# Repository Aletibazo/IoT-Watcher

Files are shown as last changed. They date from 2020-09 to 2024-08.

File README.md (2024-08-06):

# IoT-Watcher

Open source monitoring system for IT infrastructures using IoT sensors.

Related paper: https://doi.org/10.1007/978-3-031-48590-9_15

## Motivation

In Data Centers there are usually monitoring solutions offered by the manufacturer, which integrate all the equipment and sensors that make up the solution in a single system. In the CITIC data centre, all the sensors are integrated into an APC system that allows the thresholds of each type of sensor to be managed and alerts to be configured.

These proprietary solutions work very well, but it is difficult to add external elements to these systems, since they have closed APIs and it is difficult to obtain the appropriate documentation. In the specific case of the CITIC, it is desired to be able to integrate the monitoring of the servers housed in the CPD cabinets together with the monitoring of the environmental parameters of the room, thus centralising all the elements that make up the CPD and that are managed by the administrator.

## Description

This project aims to develop an open, multi-platform system that allows for the addition of different types of sensors and machines. With this secondary objective in mind, developments will be made on open hardware platforms for the sensor part and, whenever possible, open-source operating systems, libraries, external programs, etc. will be used with the goal of having a system that is as open and compatible as possible.

The monitoring server will be based on Zabbix, a widely used monitoring tool in the systems world. In the first phase, servers will be added to this system using the Zabbix agents for Windows, Linux and VMware, and their correct operation will be checked by taking data and comparing it with the servers themselves. The monitoring server forms the basis of the project, and once it is deployed and tested, the sensor section will be developed.

Sensors compatible with open-source and open-hardware Arduino boards will be used, always keeping in mind that the sensors used in this project can be replaced by others with similar characteristics. In the particular case of this project, temperature, humidity, presence and electrical consumption sensors will be used. First, the Arduino program will be developed to read data from the sensors and send it to a Raspberry Pi that will be responsible for centralizing the data from all the Arduinos in the infrastructure and sending it to the Zabbix server. Then each sensor will be placed in its corresponding place in the DC, for which issues such as autonomy, placement in racks, etc. will be taken into account.

An open-source application with the MQTT protocol will be used for data transmission between the Arduinos and the Raspberry Pi. With the rise of the IoT, multiple open-source projects have emerged to control home automation elements, so one of these projects will be used to collect all the data from the sensors and the necessary functionalities will be added to send the data to the configured Zabbix server. To achieve this communication between Raspberry and Zabbix, a specific agent will be developed.

The possibility of implementing a prediction system based on Machine Learning models that launches alerts of possible failures in the infrastructure will be considered. The system is intended to be able to alert of failures that may occur in all elements of the DC - from end-of-life warnings for disks to possible failures in the cooling system - based on historical data and real-time data.

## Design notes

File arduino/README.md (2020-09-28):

# TFM_arduinos
NodeMCU code to connect to a MQTT broker securely using TLS and sending sensors data to specified topics and displaying in on a 0.96" OLED.

You need to upload client certificate and private key as well as CA certificate into your NodeMCU's file system. Do this using ESP8266 filesystem uploader:
https://github.com/esp8266/arduino-esp8266fs-plugin
NOTE: these files must have read permissions.

Inside nodemcu_DHT22 there's code to configure a DHT22 temperature & humidity sensor.

Detailed instrucctions can be found inside each program's code.

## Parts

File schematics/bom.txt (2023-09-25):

Partlist exported from /Users/Ale/Documents/EAGLE/projects/sensor_esp8266/untitled.sch at 12/5/21 13:36

Qty Value                   Device                  Package                    Parts                  Description                                         MF         MPN      OC_FARNELL OC_NEWARK POPULARITY SPICEPREFIX
2                           10-XX                   B3F-10XX                   FLASH, RESET           OMRON SWITCH                                                   B3F-1000 176432     36M3542                         
1                           JP1E                    JP1                        TX/RX                  JUMPER                                                                                       61                    
1   100nF                   C-EUC0805               C0805                      C1                     CAPACITOR, European symbol                                                                                         
1   100nF                   CPOL-EUR/2012-12R       R/2012-12R                 C2                     POLARIZED CAPACITOR, European symbol                                                                               
1   10uF                    C-EUC0805               C0805                      C4                     CAPACITOR, European symbol                                                                                         
1   10uF 25V                C-EUC0805               C0805                      C3                     CAPACITOR, European symbol                                                                                         
4   12K                     R-US_R1206              R1206                      R2, R3, R4, R5         RESISTOR, American symbol                                                                                          
1   12K                     R-US_R1206              R1206                      R1                     RESISTOR, American symbol                                                                               R          
1   DISPLAY-OLED-128X64-I2C DISPLAY-OLED-128X64-I2C DISPLAY-OLED-128X64-I2C    OLED                   128x64 Dot Matrix OLED Module based on SSD1306 chip                                                                
1   ESP-12E/F               ESP-12E/F               ESP-12E                    IC1                                                                                                                                       
1   HT7333                  HT7333                  SOT-89                     HT7333                                                                                                                                    
4   JST-XH-03-PIN-LONG-PAD  JST-XH-03-PIN-LONG-PAD  JST-XH-03-PACKAGE-LONG-PAD 1W, LED, PIR, TEMP     JST XH Connector 2 Pin                                                                                             
1   JST-XH-07-PIN-LONG-PAD  JST-XH-07-PIN-LONG-PAD  JST-XH-07-PACKAGE-LONG-PAD D5/D6/D7/D8/GND/3V3/5V JST XH Connector 2 Pin                                                                                             
1   MICRO-USBV2             MICRO-USBV2             MICRO-USB-2                USB                    Micro USB B connector                                                                                              
1   SMAJ5.0A                SMAJ5.0A                DO214AC                    D1                     SMAJ Series TVS Diodes                              Littelfuse SMAJ5.0A 1827607    71J2029

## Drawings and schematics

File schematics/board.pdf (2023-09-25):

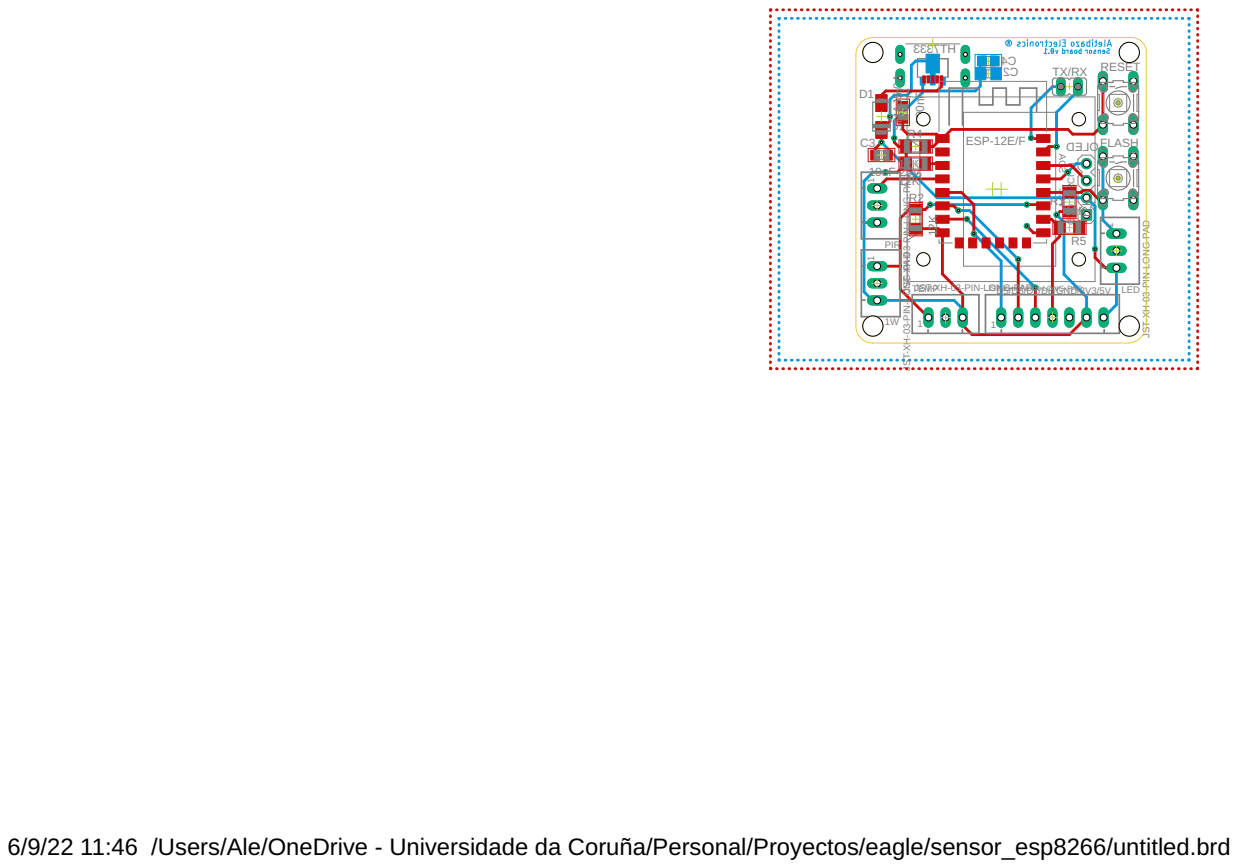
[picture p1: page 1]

JST-XH-03-PIN-LONG-PAD

TEMP

JST-XH-07-PIN-LONG-PAD

6/9/22 11:46 /Users/Ale/OneDrive - Universidade da Coruña/Personal/Proyectos/eagle/sensor_esp8266/untitled.brd

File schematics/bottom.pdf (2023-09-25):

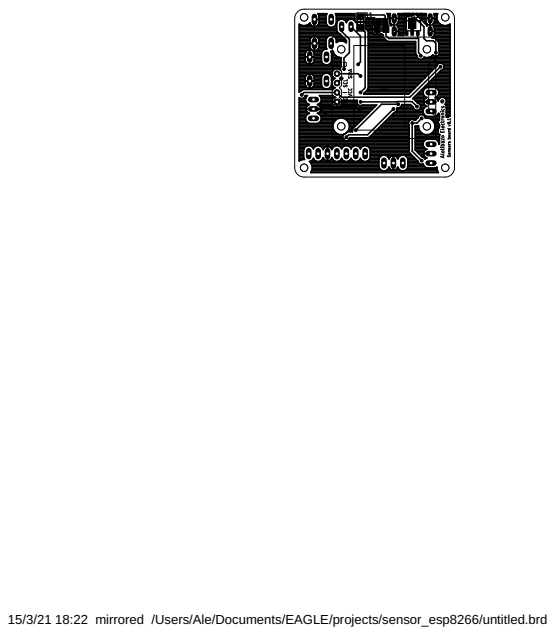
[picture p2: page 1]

15/3/21 18:22 mirrored /Users/Ale/Documents/EAGLE/projects/sensor_esp8266/untitled.brd

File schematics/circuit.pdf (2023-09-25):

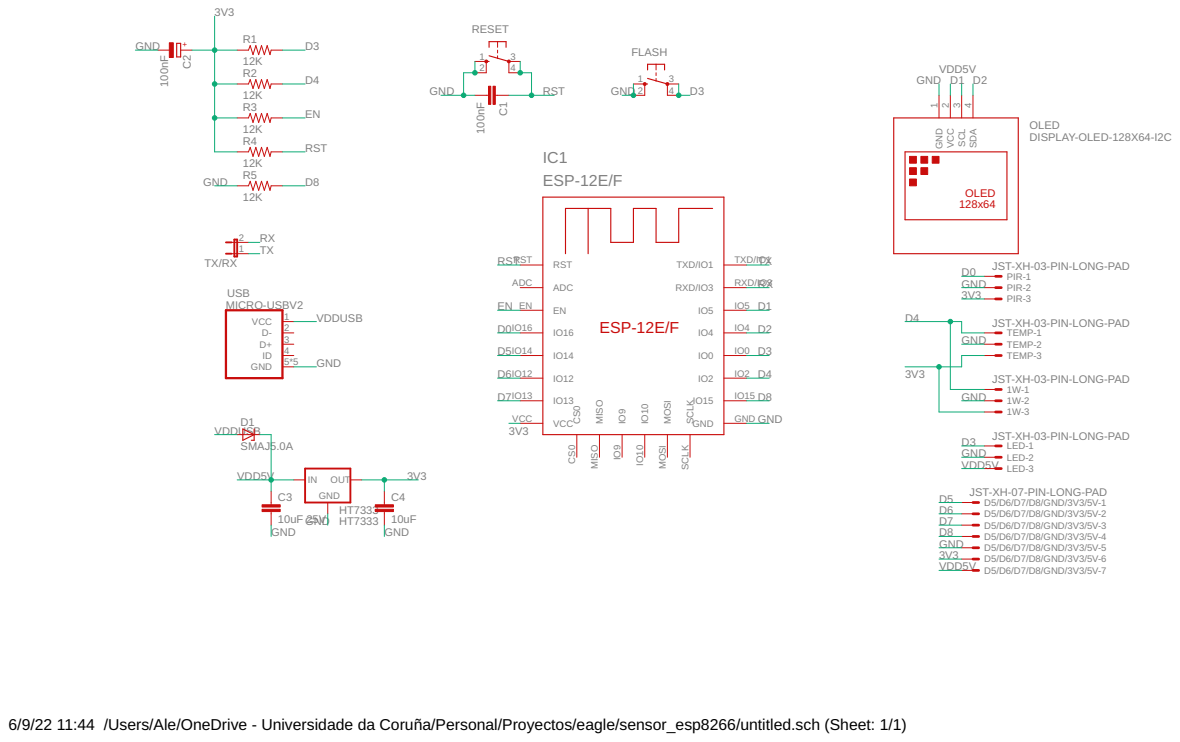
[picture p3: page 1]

JST-XH-03-PIN-LONG-PAD
TEMP-1 TEMP-2 TEMP-3

6/9/22 11:44 /Users/Ale/OneDrive - Universidade da Coruña/Personal/Proyectos/eagle/sensor_esp8266/untitled.sch (Sheet: 1/1)

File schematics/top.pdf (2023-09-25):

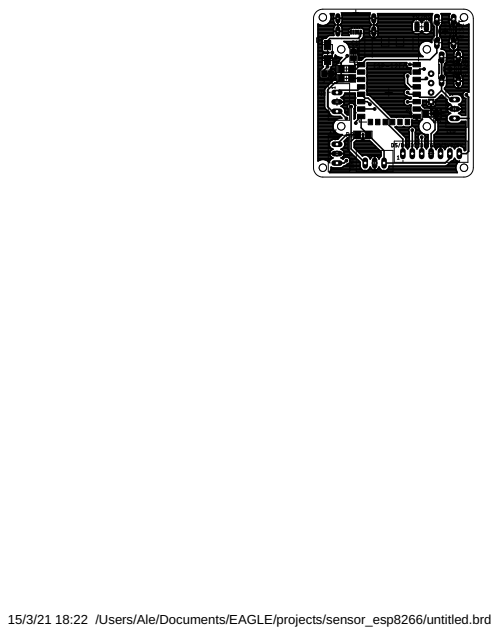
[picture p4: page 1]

15/3/21 18:22 /Users/Ale/Documents/EAGLE/projects/sensor_esp8266/untitled.brd


15/3/21 18:22 mirrored /Users/Ale/Documents/EAGLE/projects/sensor_esp8266/untitled.brd

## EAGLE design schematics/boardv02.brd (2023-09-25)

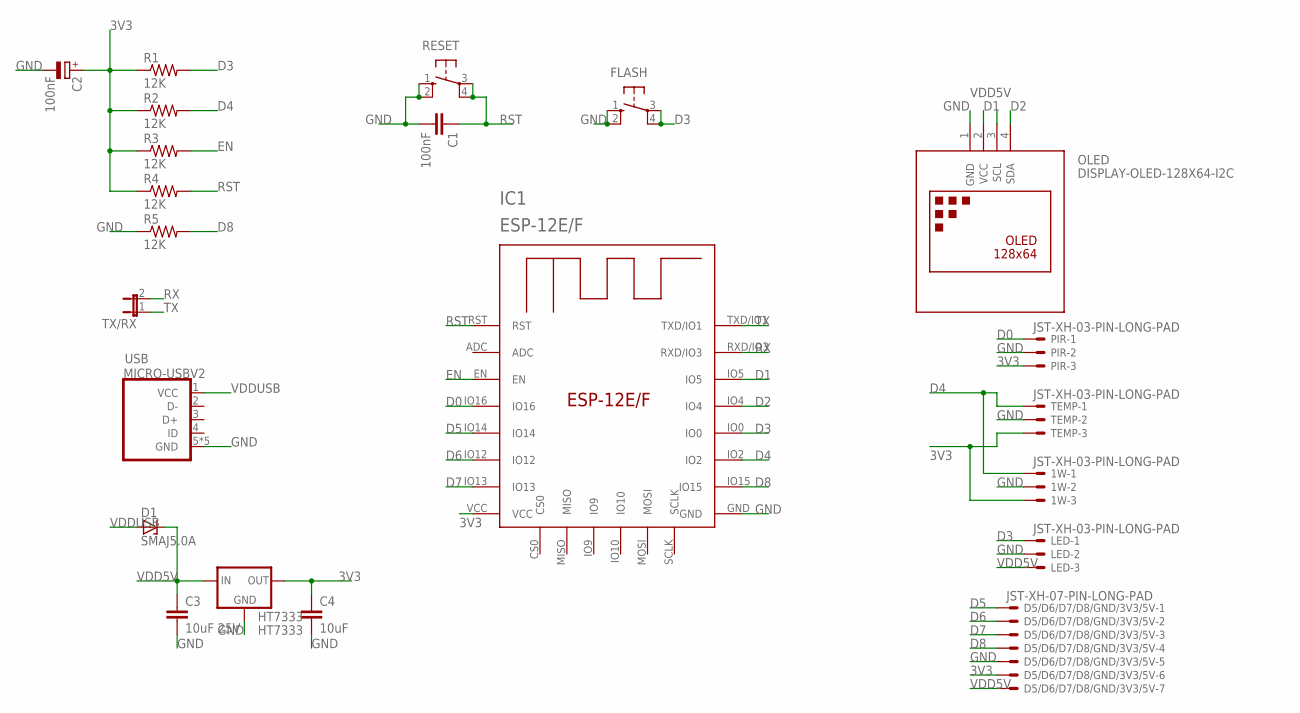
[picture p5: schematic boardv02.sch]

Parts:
1W: JST-XH-03-PIN-LONG-PAD; JST-XH-03-PACKAGE-LONG-PAD
C1: 100nF; C0805
C2: 100nF; R/2012-12R
C3: 10uF 25V; C0805
C4: 10uF; C0805
D1: SMAJ5.0A; DO214AC
D5/D6/D7/D8/GND/3V3/5V: JST-XH-07-PIN-LONG-PAD; JST-XH-07-PACKAGE-LONG-PAD
FLASH: 10-XX; B3F-10XX
HT7333: HT7333; SOT-89
IC1: ESP-12E/F; ESP-12E
LED: JST-XH-03-PIN-LONG-PAD; JST-XH-03-PACKAGE-LONG-PAD
OLED: DISPLAY-OLED-128X64-I2C
PIR: JST-XH-03-PIN-LONG-PAD; JST-XH-03-PACKAGE-LONG-PAD
R1, R2, R3, R4, R5: 12K; R1206
RESET: 10-XX; B3F-10XX
TEMP: JST-XH-03-PIN-LONG-PAD; JST-XH-03-PACKAGE-LONG-PAD
TX/RX: JP1E; JP1
USB: MICRO-USBV2; MICRO-USB-2

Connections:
3V3: 1W.3, C2.+, C4.1, D5/D6/D7/D8/GND/3V3/5V.6, HT7333.1 (OUT), IC1.VCC, PIR.3, R1.1, R2.1, R3.1, R4.1, TEMP.3
D0: IC1.IO16, PIR.1
D1: IC1.IO5, OLED.3 (SCL)
D2: IC1.IO4, OLED.4 (SDA)
D3: FLASH.3, FLASH.4 (P1), IC1.IO0, LED.1, R1.2
D4: 1W.1, IC1.IO2, R2.2, TEMP.1
D5: D5/D6/D7/D8/GND/3V3/5V.1, IC1.IO14
D6: D5/D6/D7/D8/GND/3V3/5V.2, IC1.IO12
D7: D5/D6/D7/D8/GND/3V3/5V.3, IC1.IO13
D8: D5/D6/D7/D8/GND/3V3/5V.4, IC1.IO15, R5.2
EN: IC1.EN, R3.2
GND: 1W.2, C1.2, C2.-, C3.2, C4.2, D5/D6/D7/D8/GND/3V3/5V.5, FLASH.1 (S), FLASH.2 (S1), HT7333.2 (GND), IC1.GND, LED.2, OLED.1 (GND), PIR.2, R5.1, RESET.1 (S), RESET.2 (S1), TEMP.2, USB.5 (GND), USB.P$1 (GND), USB.P$2 (GND), USB.P$3 (GND), USB.P$4 (GND)
RST: C1.1, IC1.RST, R4.2, RESET.3, RESET.4 (P1)
RX: IC1.RXD/IO3, TX/RX.2
TX: IC1.TXD/IO1, TX/RX.1
VDD5V: C3.1, D1.C, D5/D6/D7/D8/GND/3V3/5V.7, HT7333.3 (IN), HT7333.4 (IN), LED.3, OLED.2 (VCC)
VDDUSB: D1.A, USB.1 (VCC)

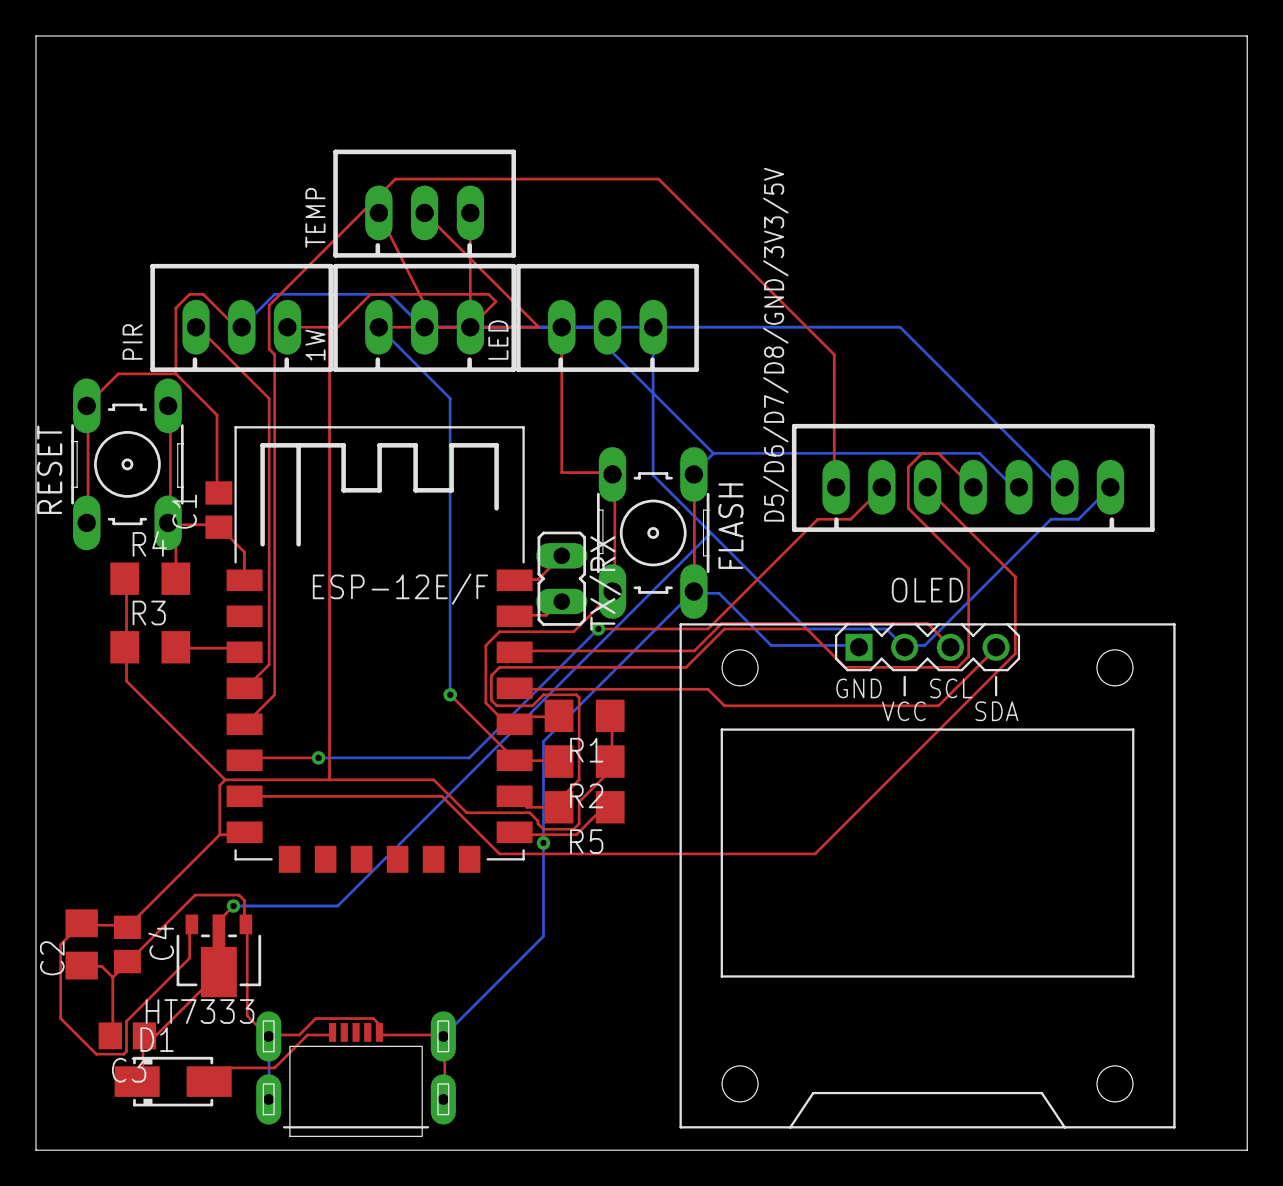
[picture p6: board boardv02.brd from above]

Board: 2 copper layers, 67.3 x 61.9 mm, 22 parts (0 on the bottom side), 17 nets.

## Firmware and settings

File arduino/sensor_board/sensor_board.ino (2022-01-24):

/*
* This is the firmware for Aletibazo Electronics Sensor Board v0.1
* 
* Pinout correspondence between the board and the ESP8266:
*   * PIR      -> D0
*   * LED      -> D3
*   * 1W, TEMP -> D4
*   * HUMIDITY -> D5
*   
* This program connects to a MQTT broker using TLS
* and sends data from DS18B20, DHT22 and PIR sensors to specified topics. It also
* displays sensors data and other info on a 128x32 OLED display.
* 
* Don't forget to set variables to connect to access point and MQTT broker.
* You need to upload client.crt, client.key and ca.crt to Node MCU's file system.
* These need to be issued by your broker's server, as detailed here:
* https://gitlab.citic.udc.es/a.mosteiro/tfm/-/wikis/Aplicaciones-dom%C3%B3tica
* To upload files to the file system, follow this guide: 
* https://github.com/esp8266/arduino-esp8266fs-plugin
* 
* Note that MQTTServer variable must be a domain name, not an IP address.
* IPSET_DNS must be a DNS server that can resolve your broker's name.
* 
* Author: Ale Mosteiro
* Mail:   a.mosteiro@udc.es
* 
*/

#include <ESP8266WiFi.h>
#include <PubSubClient.h>
#include <Wire.h>
#include <DallasTemperature.h>
#include <OneWire.h>
#include <U8g2lib.h>
#include <SPI.h>
#include <DHTesp.h>

// PIR sensor is connected to pin D0
int PIR_SENSOR = D0;
// DHT11 sensor connected to pin D5
int DHT_SENSOR = D5;
DHTesp dht;

// Data wire is plugged into pin D4 on the NodeMCU
#define ONE_WIRE_BUS D4
// Setup a oneWire instance to communicate with any OneWire devices 
// (not just Maxim/Dallas temperature ICs)
OneWire oneWire(ONE_WIRE_BUS);
// Pass our oneWire reference to Dallas Temperature.
DallasTemperature sensors(&oneWire);

// Set OLED type
U8G2_SSD1306_128X32_UNIVISION_F_HW_I2C u8g2(U8G2_R0);

/**
 * Customize this settings 
 */
const char* ssid = "SSID-Name";
const char* password = "SSID-Password";
#define IPSET_STATIC { xxx, xxx, xxx, xxx }
#define IPSET_GATEWAY { xxx, xxx, xxx, xxx }
#define IPSET_SUBNET { xxx, xxx, xxx, xxx }
#define IPSET_DNS { xxx, xxx, xxx, xxx }


// TODO Change this to parametrize ClientName so it needs to be replaced only once
const char* ClientName = "RackNumber";
const char* MQTTServer = "your-domain.org";

char* TopicSub = "cpd/RackNumber/led";
char* TopicConfigTemp = "cpd/sensor/RackNumberTemp/config";
char* PayloadConfigTemp = "{\"device_class\": \"temperature\", \"name\": \"RackNumberTemperature\", \"state_topic\": \"cpd/sensor/RackNumber/state\", \"unit_of_measurement\": \"°C\", \"value_template\": \"{{ value_json.temperature }}\" }";
char* TopicConfigHumdt = "cpd/sensor/RackNumberHumdt/config";
char* PayloadConfigHumdt = "{\"device_class\": \"humidity\", \"name\": \"RackNumberHumidity\", \"state_topic\": \"cpd/sensor/RackNumber/state\", \"unit_of_measurement\": \"%\", \"value_template\": \"{{ value_json.humidity }}\" }";
char* StateTopic = "cpd/sensor/RackNumber/state";
char* TopicConfigPIR = "cpd/binary_sensor/RackNumberPIR/config";
char* PayloadConfigPIR = "{\"device_class\": \"motion\", \"name\": \"RackNumberPIR\", \"state_topic\": \"cpd/binary_sensor/RackNumberPIR/state\" }";
char* StateTopicPIR = "cpd/binary_sensor/RackNumberPIR/state";

/**
 * End of customization
 */

byte IPStatic[] = IPSET_STATIC;
byte IPGateway[] = IPSET_GATEWAY;
byte IPSubnet[] = IPSET_SUBNET;
byte IPDNS[] = IPSET_DNS;
  
WiFiClientSecure ESPClient;
PubSubClient client(MQTTServer, 8883, ESPClient);

int lastMsg = 0;
boolean configured = false;

char msg[50];

float t;
float h;
char buff[5];

int buttonState = 0;

void setup() {
  pinMode(LED_BUILTIN, OUTPUT);     // Initialize the LED_BUILTIN pin as an output
  
  Serial.begin(115200);

  u8g2.begin();
  dht.setup(DHT_SENSOR, DHTesp::DHT11);

  printInfo("Setting up...");
  // Connect WiFi
  printInfo("Connecting WiFi");
  setupWiFi();
  delay(1000);
  // Get time from SNTP Server
  printInfo("Get SNTP time");
  getTime();
  delay(1000);

  // Load certs for TLS
  printInfo("Load certs");
  loadCerts();
  delay(1000);
  
  //dht.begin();
  sensors.begin();

  client.setCallback(callback);
}

void loop() {  
  if (!client.connected()) {
    printInfo("Connect broker");
    reconnect();
  }
  client.loop();

  long now = millis();

  // Send sensor config on power on
  if (!configured) {
    configured = true;

    sendmqttMsg(TopicConfigTemp, PayloadConfigTemp);
    sendmqttMsg(TopicConfigHumdt, PayloadConfigHumdt);
    sendmqttMsg(TopicConfigPIR, PayloadConfigPIR);
  }
  
  // Send sensors data every 5 sec
  if (now - lastMsg > 5000) {
    String payload = String();
    lastMsg = now;

    // Obtain temperature from DS18B20 1-wire sensor
    sensors.requestTemperatures();
    t = sensors.getTempCByIndex(0);
    // Add temperature to payload
    payload = "{ \"temperature\": " + String(t, 2);
    // Obtain humidity from DHT22 sensor
    h = dht.getHumidity();
    // If we can't get data from the sensor, we send -127
    String hmdt = (isnan(h) == 1) ? "-127" : String(h, 2);
    // Add humidity to payload
    payload = payload + ", \"humidity\": ";
    payload = payload + hmdt;
    // Add presence to payload, getting value from digital pin
    // Close payload string, send it to StateTopic MQTT topic
    payload = payload + " }";
    // Send MQTT payload for temperature and humidity
    sendmqttMsg(StateTopic, payload);

    // Prepare payload for PIR, reading data from DHT22
    String motion = (digitalRead(PIR_SENSOR) == 1) ? "ON" : "OFF";
    payload = "{ \"state\": \"" + motion;
    // Close payload string, send it to StateTopic MQTT topic
    payload = payload + "\" }";
    // Send MQTT payload for PIR
    sendmqttMsg(StateTopicPIR, motion);
    
    
    // Print data to OLED
    printData(t, h);
    
  }
}

// Function to display set up information
// Given char must be 16chars max
void printInfo(const char *s){
  u8g2.clearBuffer();
  u8g2.setFont(u8g2_font_t0_16_tf);
  u8g2.drawStr(0, 12, ClientName);
  u8g2.drawStr(0, 24, s);
  u8g2.sendBuffer();
}
// Function to display set up information
// Given char must be 16chars max
void printData(float temperature, float humidity){
  u8g2.clearBuffer();
  u8g2.setFont(u8g2_font_t0_16_tf);
  u8g2.setCursor(0, 12);
  u8g2.print(ClientName);
  u8g2.setFont(u8g2_font_profont10_tf);
  u8g2.setCursor(0, 20);
  u8g2.print("T: ");
  u8g2.print(temperature);
  u8g2.print(" C");
  u8g2.setCursor(0, 28);
  u8g2.print("H: ");
  u8g2.print(humidity);
  u8g2.print(" %");
  u8g2.sendBuffer();
}


void setupWiFi() {

  delay(10);
  // We start by connecting to a WiFi network
  Serial.println();
  Serial.print("Connecting to ");
  Serial.println(ssid);

  WiFi.mode(WIFI_STA);
  WiFi.begin(ssid, password);
  WiFi.disconnect();

  WiFi.begin(ssid, password);
  WiFi.config(IPAddress(IPStatic), IPAddress(IPGateway), IPAddress(IPSubnet), IPAddress(IPDNS));
  while (WiFi.status() != WL_CONNECTED) {
    delay(500);
    Serial.print(".");
  }

  Serial.println("");
  Serial.println("WiFi connected");
  Serial.println("IP address: ");
  Serial.println(WiFi.localIP());
}

void getTime(){
  // Synchronize time using SNTP. This is necessary to verify that
  // the TLS certificates offered by the server are currently valid.
  Serial.print("Setting time using SNTP");
  configTime(8 * 3600, 0, "es.pool.ntp.org");
  time_t now = time(nullptr);
  while (now < 1000) {
    delay(500);
    Serial.print(".");
    now = time(nullptr);
  }
  Serial.println("");
  struct tm timeinfo;
  gmtime_r(&now, &timeinfo);

  Serial.print("Current time: ");
  Serial.print(asctime(&timeinfo));
  printInfo(asctime(&timeinfo));
}

// Load Certificates
void loadCerts() {
  
  if (!SPIFFS.begin()) {
   Serial.println("Failed to mount file system");
   return;
  }
  
  // Load client certificate file from SPIFFS
  File cert = SPIFFS.open("/client.crt", "r"); //replace client.crt with your uploaded file name
  if (!cert)
    Serial.println("Failed to open cert file");
  else
    Serial.println("Success to open cert file");

  delay(1000);

  // Set client certificate
  if (ESPClient.loadCertificate(cert)){
    Serial.println("cert loaded");
  } else
    Serial.println("cert not loaded");

  // Load client private key file from SPIFFS
  File private_key = SPIFFS.open("/client.key", "r"); //replace client.key with your uploaded file name
  if (!private_key)
    Serial.println("Failed to open private cert file");
  else
    Serial.println("Success to open private cert file");

  delay(1000);

  // Set client private key
  if (ESPClient.loadPrivateKey(private_key)){
    Serial.println("private key loaded");
  }
  else
    Serial.println("private key not loaded");

  // Load CA file from SPIFFS
  File ca = SPIFFS.open("/ca.crt", "r"); //replace ca.crt with your uploaded file name
  if (!ca)
    Serial.println("Failed to open ca ");
  else
    Serial.println("Success to open ca");
  delay(1000);

  // Set server CA file
  if(ESPClient.loadCACert(ca)){
    Serial.println("ca loaded");
  } else
    Serial.println("ca failed");
}

// Callback function to activate LED if there are errors
void callback(char* topic, byte* payload, unsigned int length) {
  Serial.print("Message arrived [");
  Serial.print(topic);
  Serial.print("] ");
  for (int i = 0; i < length; i++) {
    Serial.print((char)payload[i]);
  }
  Serial.println();

// Switch on the LED if an 1 was received as first character
  if ((char)payload[0] == '1')
    digitalWrite(LED_BUILTIN, LOW);
  else
    digitalWrite(LED_BUILTIN, HIGH);
}

void reconnect() {
  // Loop until we're reconnected
  while (!client.connected()) {
    Serial.print("Attempting MQTT connection...");
    // Attempt to connect
    if (client.connect(ClientName)) {
        delay(1000);
      Serial.println("connected");
      // Once connected, publish an announcement...
      client.publish("connected", ClientName);
      // ... and / or resubscribe
      client.subscribe(TopicSub);
    } else {
      Serial.print("failed, rc=");
      Serial.print(client.state());
      Serial.println(" try again in 5 seconds");
      // Wait 5 seconds before retrying
      delay(5000);
    }
  }
}

void sendmqttMsg(char* topictosend, String payload) {

  if (client.connected()) {
      Serial.print("Sending payload: ");
      Serial.print(payload);

    unsigned int msg_length = payload.length();

      Serial.print(" length: ");
      Serial.println(msg_length);

    byte* p = (byte*)malloc(msg_length);
    memcpy(p, (char*) payload.c_str(), msg_length);

    if ( client.publish(topictosend, p, msg_length)) {
        Serial.println("Publish ok");
      free(p);
      //return 1;
    } else {
        Serial.println("Publish failed");
      free(p);
      //return 0;
    }
  }
}

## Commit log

2021-05-21 Create sensor_board.ino
    Added sensor_board.ino, intended to be the official firmware version for the sensor board designed for this project, integrating DS18B20, PIR and LED
2021-11-22 Update sensor_board.ino
    Several changes here.
    Implemented MQTT messaging system, so HomeAssistant can auto discover. Note that topic prefix for discovery has to be set on HomeAssistant configuration.yaml so it matches the one we use here.
    Added PIR sensor.
    Added humidity sensor using DHT library. Set on D5.
    Changes on display settings, using print instead of drawStr now.
2022-01-24 Replaced DHT.h library with DHTesp.h, now DHT11 sensor is working on D5
    [sensor_board.ino]
2023-09-25 Added SensorBoard Eagle Project, witch schematics for the custom board. Edited gitignore file so it doesn't upload unnecesary files from Eagle.
    [DRILEGEND.CFG, boardv01.brd, boardv02.brd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]

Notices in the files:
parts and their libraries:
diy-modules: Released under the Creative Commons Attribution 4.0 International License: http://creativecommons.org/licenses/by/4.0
